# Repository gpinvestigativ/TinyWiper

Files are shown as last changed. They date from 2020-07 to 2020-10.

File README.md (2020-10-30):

# TinyWiper - a portable SD card wiper

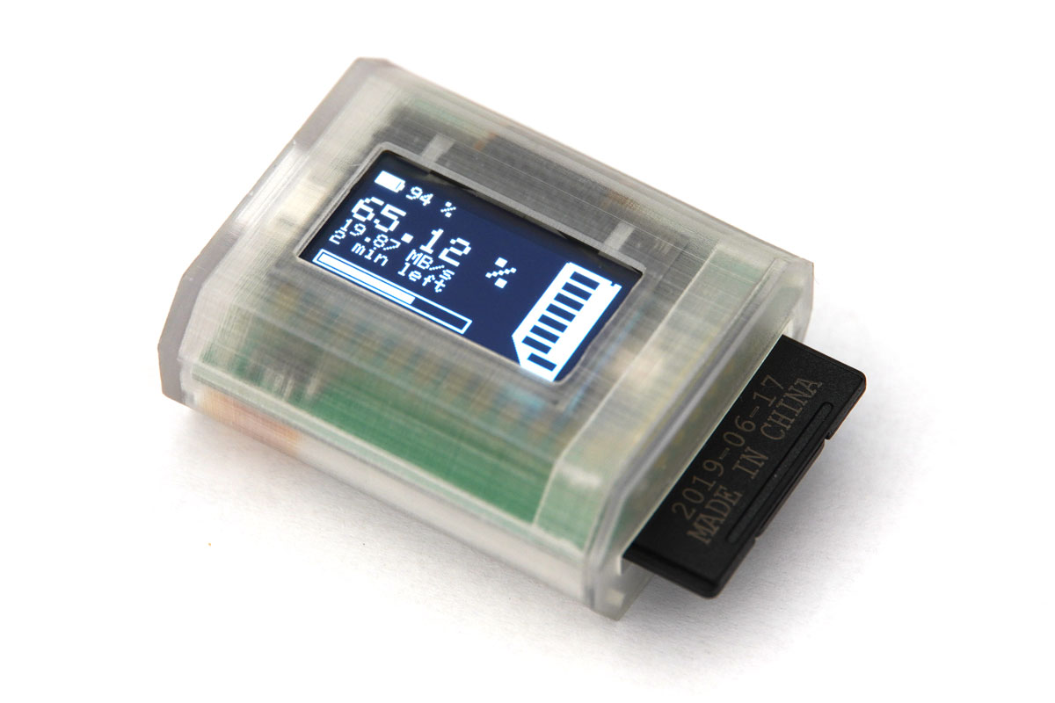
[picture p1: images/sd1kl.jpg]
Image of TinyWiper


The TinyWiper is a small, battery powered device which securely deletes your SD cards by overwriting the whole card with randomly generated data.  

> *Note:* this is an successor project to the [SDCardWiper](https://github.com/gpinvestigativ/SDCardWiper) Project, which is based on a Raspberry Pi Zero and readily available parts.  

Just formating your SD card does not delete its contents, it just makes them invisible within the filebrowser of your operating system. Forensic software can often easily reconstruct data on deleted or formated SD cards.  

If you want to make sure that your data can not be reconstructed, this device will securely erase your SD cards.

## Hardware

* Teensy 4.0 as MCU
* Custom PCB
* 128x64 I2C OLED Display
* Full Size SD Card Slot
* 400 mAh Lipo Battery ~ 2h battery life
* Mirco USB for fimware update & battery charging
* Hardware on/off switch
* 3D printed case

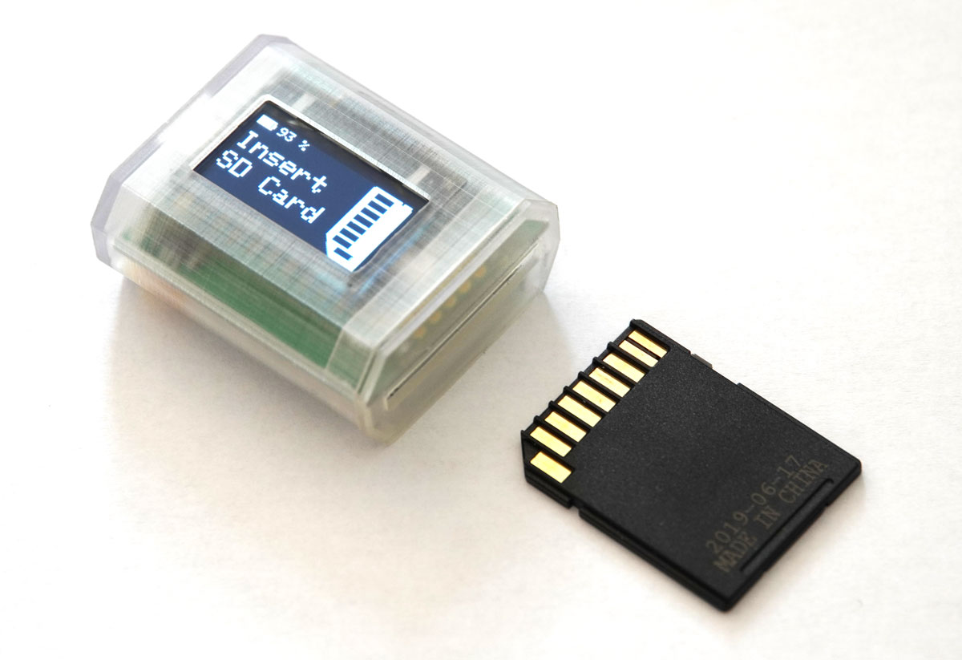
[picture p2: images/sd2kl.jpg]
Image of TinyWiper


## Software

* True random number generator used to initialize PRNG
* automatically detect SD card, start wiping automatically after timeout
* every Nth 512byte Block, generate a new random buffer (for speedup purposes currently every 10th block)
* keep track of successfully written blocks, try to re-write failed blocks at the end
* format card after wiping
* shows successrate at the end of the process

# DIY Version
Part of the reason there is a custom PCB for the TinyWiper was, that at the time of development only the Teensy4.0 was available which had it's high speed SDIO pins at a very DIY inconvenient place.  
Recently the Teensy4.1 was released which conveniently has a micro SD card slot. Therefore I decided to make a compatible firmware for the T4.1 for people who want to build a quick DIY version of the TinyWiper. You can find this firmware in the [t41port](https://github.com/gpinvestigativ/TinyWiper/tree/t41port) branch.

## Setup
If you don't want to build the firmware yourself you can find precompiled binaries under the releases tab.

To flash the binaries you need the the [Teensy Loader](https://www.pjrc.com/teensy/loader.html) Application.

**Caution:** the button on the Teensy is a reset button, be careful not to press it accidentally while wiping an SD Card. You could also make a little protective cover for the button.

LED pattern | meaning 
---|---
t41idle | Idle - insert SD card
t41idle | wiping - 10% done 
t41idle | wiping - 80% done 
t41idle | wiping finished - remove sd card

## Q&A

*Q: Why not use a secure erase software on a computer like the security options within macs disk manager?*  
A: While it is totaly viable to use secure erase software options for this task, the TinyWiper has 3 major advantages:
* TinyWiper is highly portable. You can carry it in your pocket in the field and use it standalone without having to use a computer.
* Securely wiping SD cards is time consuming. It easily blocks the sd card slot on your computer for several hours. Overwriting a 64GB SD card can take between 1-2 hours, 400GB multiple hours.
* Software that runs on your computer can much easier be infiltrated by a virus or an attacker. The TinyWiper is an unteathered device, which makes it impossible to hack without physical access to it.

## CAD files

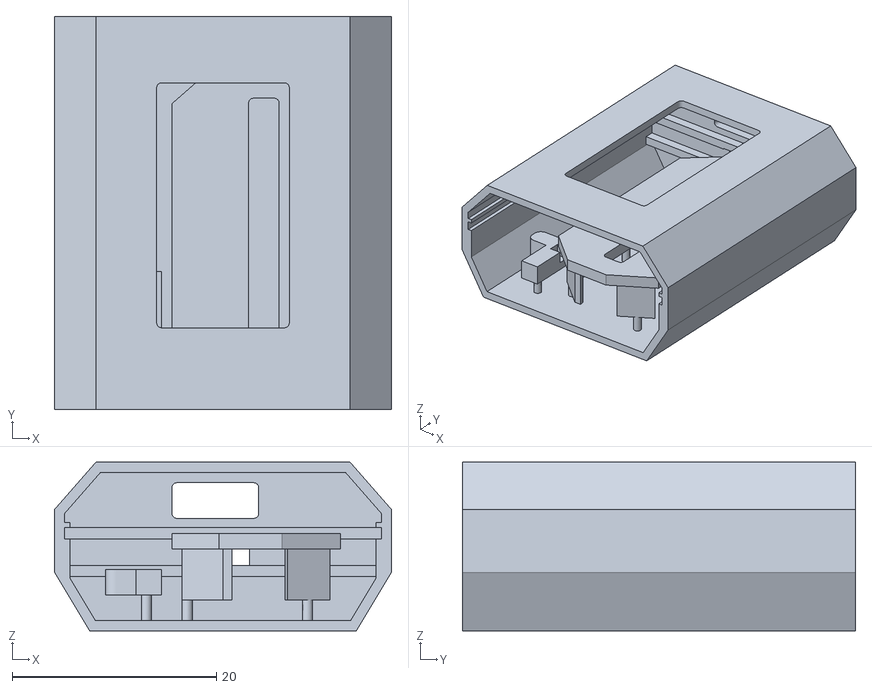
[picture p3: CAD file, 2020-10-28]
hardware/case.stl
33.0 x 38.5 x 16.5

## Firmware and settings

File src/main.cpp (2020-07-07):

#include <Arduino.h>
#include <vector>

#include "SdFat.h"
#include <sdios.h>
#include "FreeStack.h"
#include <Wire.h>
#include <Adafruit_GFX.h>
#include <Adafruit_SSD1306.h>

#include "data.h"
#include <trng.h>

//#define DEBUG_BATT
#define FORMATCARD

#define VERSION 0.2

const float analogDivider = 160.0f;

#define cardDetectPin 23
#define writeProtectPin 22
#define DISPLAY_RST_PIN 15

const size_t BUF_SIZE = 512;

#define SD_CONFIG SdioConfig(FIFO_SDIO)

//==============================================================================
// End of configuration constants.
//------------------------------------------------------------------------------

// Insure 4-byte alignment.
uint32_t buf32[(BUF_SIZE + 3) / 4];
uint8_t* buf = (uint8_t*)buf32;

SdioCard sd;

Adafruit_SSD1306 display(128, 64, &Wire, DISPLAY_RST_PIN, 4000000UL, 100000UL);

ArduinoOutStream cout(Serial);

void cidDmp() {
  cid_t cid;
  if (!sd.readCID(&cid)) {
    cout << "CID Error" << endl;
  }
  cout << F("\nManufacturer ID: ");
  cout << hex << int(cid.mid) << dec << endl;
  cout << F("OEM ID: ") << cid.oid[0] << cid.oid[1] << endl;
  cout << F("Product: ");
  for (uint8_t i = 0; i < 5; i++) {
    cout << cid.pnm[i];
  }
  cout << F("\nVersion: ");
  cout << int(cid.prv_n) << '.' << int(cid.prv_m) << endl;
  cout << F("Serial number: ") << hex << cid.psn << dec << endl;
  cout << F("Manufacturing date: ");
  cout << int(cid.mdt_month) << '/';
  cout << (2000 + cid.mdt_year_low + 10 * cid.mdt_year_high) << endl;
  cout << endl;
}

void drawBattery(int offX = 0, int offY = 0) {
  static int battLutOffset = 540;
  int aread0 = analogRead(0);

  #ifdef DEBUG_BATT
  cout << F("Aread 0: ") << aread0 << endl;
  #endif

  int battLutIdx = aread0 - battLutOffset;
  battLutIdx = constrain(battLutIdx, 0, 130);
  int battPercent = battLut[battLutIdx];
  int battBarValue = round((float)battPercent / 100.0f * 11);
  display.drawRect(offX, offY, 12, 7, SSD1306_WHITE);
  display.fillRect(offX, offY, battBarValue, 7, SSD1306_WHITE);
  display.drawLine(offX + 12, offY + 2, offX + 12, offY + 4, SSD1306_WHITE);
  display.setTextSize(1);
  display.setCursor(offX + 17, offY);
  display.setTextColor(SSD1306_WHITE);
  display.print(battPercent); display.print(" %");
}

void showStartScreen() {
  static int aniCount = 0;
  display.clearDisplay();
  display.drawBitmap(128 - (aniCount > 35 ? 35 : aniCount), 1, sdCardBitmap, 77, 62, SSD1306_WHITE);
  aniCount += 1;
  if (aniCount > 50) aniCount = 0;
  drawBattery();
  display.setTextColor(SSD1306_WHITE);
  display.setTextSize(2);
  display.setCursor(0, 15); display.print("Insert");
  display.setCursor(0, 35); display.print("SD Card");
  display.display();
}

//------------------------------------------------------------------------------
void setup() {
  display.begin(SSD1306_SWITCHCAPVCC, 0x3C);
  display.setRotation(2);

  // display.clearDisplay();
  // display.drawBitmap(0, 0, gpi, 128, 64, SSD1306_WHITE);
  // display.display();
  // delay(200);
  
  display.clearDisplay();
  display.drawBitmap(0, 0, tinyWiper, 128, 64, SSD1306_WHITE);
  display.setTextColor(SSD1306_WHITE);
  display.setCursor(105, 49);
  display.setTextSize(1);
  display.print(VERSION,1);
  display.display();


  pinMode(cardDetectPin, INPUT_PULLUP);
  pinMode(writeProtectPin, INPUT_PULLUP);

  Serial.begin(115200);
  //while (!Serial);

  // use uppercase in hex and use 0X base prefix
  cout << uppercase << showbase << endl;

  trng_init();
  uint32_t tword = trng_word();
  //cout << "random seed: " << tword << endl;
  srandom(tword);
  delay(1000);
}
//------------------------------------------------------------------------------
void loop() {
  uint32_t t = 0;
  int durationMinutes = 0;
  bool writable = false;
  bool randWriteCompleted = false;
  bool formatCompleted = false;

  //wait for card insert
  while (digitalRead(cardDetectPin) == 1) {
    showStartScreen();
    delay(50);
  }
  delay(100);

  #ifdef WRITEPROTECTCHECK
  if (digitalRead(writeProtectPin) == 0) {
    delay(500);
    if (digitalRead(writeProtectPin) == 0)
      writable = true;
    else
      writable = false;

  } else {
    writable = false;
  }
  #else
  writable = true;
  #endif


  while (!sd.begin(SD_CONFIG)) {
    if (digitalRead(cardDetectPin) == 1) break;
  }

  cout << F("Card size: ") << sd.sectorCount() * 512E-9;
  cout << F(" GB (GB = 1E9 bytes)") << endl;
  cout << F("Speed: ") << sd.kHzSdClk() << F(" kHz") << endl;
  cout << F("sectorCount: ") << sd.sectorCount() << endl;

  cidDmp();

  //pre wipe info screen
  int aniCount = 64;
  while (aniCount > 0) {
    display.clearDisplay();
    drawBattery();
    display.drawBitmap(100, 1, sdCardBitmap, 77, 62, SSD1306_WHITE);
    display.setTextColor(SSD1306_WHITE);
    display.setCursor(0, 15);
    display.setTextSize(2);
    display.print(sd.sectorCount() * 512E-9); display.println(" GB");
    display.setTextSize(1);
    display.print(sd.kHzSdClk() / 1000); display.println(" MHz");
    if (writable)
    {
      display.setCursor(0, 55);
      display.println("Starting Wipe...");
      display.drawLine(0, 63, 128 - aniCount * 2, 63, SSD1306_WHITE);
      aniCount--;
    } else {
      display.setCursor(0, 56);
      display.println("SD Card locked");
    }
    display.display();
    delay(30);
    if (digitalRead(cardDetectPin) == 1) break;
  }

  //actual wiping
  int failedSectorCount = 0;
  std::vector<unsigned int> failedSectors;
  #if 1
  if (digitalRead(cardDetectPin) == 0) {
    cout << F("Starting full disk wipe") << endl << endl;
    t = millis();
    uint32_t lastT = t;
    for (unsigned int i = 0; i < sd.sectorCount(); i++) {
      if (i % 10 == 0) {
        for (size_t i = 0; i < BUF_SIZE/4; i++) {
          buf32[i]= random();
        }
      }
      auto startus = micros();
      bool writeStatus = sd.writeSector(i, buf);

      if(!writeStatus){ //error handling
        cout << (int)sd.errorCode() << " ";
        printSdErrorSymbol(&Serial, sd.errorCode());
        cout << " ";
        printSdErrorText(&Serial, sd.errorCode());
        cout << endl;
        failedSectorCount++;
        failedSectors.push_back(i);
      }
      if(micros()-startus > 888888){ //hacky fix for random SD Card errors
        cout << "restart sd " << i << endl;
        sd.begin(SD_CONFIG);
      }

      if ((millis() - lastT) > 1000) {
        lastT = millis();
        uint32_t usedtime = millis() - t;
        double msPerSector = (double)usedtime / (double)i;
        uint32_t sectorsLeft = sd.sectorCount() - i;

        //cout << ((double)i/(double)sd.sectorCount())*100 << " % - " << i*512E-3/usedtime << " MB/s - " << usedtime << " " << msPerSector << " " << sectorsLeft << " " << (sectorsLeft*msPerSector)/60000 << " min left"<< endl;

        display.clearDisplay();
        drawBattery();
        display.drawBitmap(100, 1, sdCardBitmap, 77, 62, SSD1306_WHITE);
        display.setTextColor(SSD1306_WHITE);
        display.setCursor(0, 15);
        display.setTextSize(2);
        double progress = ((double)i / (double)sd.sectorCount()) * 100;
        display.print(progress); display.println(" %");
        display.setTextSize(1);
        display.print(i * 512E-3 / usedtime); display.println(" MB/s");
        display.print((int)((sectorsLeft * msPerSector) / 60000)); display.println(" min left");
        display.drawRect(0, 52, 80, 8, SSD1306_WHITE);
        display.fillRect(2, 54, (int)round(progress * 0.76), 4, SSD1306_WHITE);
        display.display();
        if (digitalRead(cardDetectPin) == 1) break;
      }
      if (digitalRead(cardDetectPin) == 1) break;
      if (i == sd.sectorCount() - 1)
        randWriteCompleted = true;
    }
  }
  #endif

  //retry failed Sectors
  #if 1
  //for(int x = 0; x < 8000; x++)failedSectors.push_back(x);

  cout << "retry " << failedSectors.size() << " failed sectors";
  uint32_t lastT = t;
  uint32_t curSector = 0;
  for(auto sec : failedSectors){
    int secRetries = 5;
    curSector++;
    for (size_t i = 0; i < BUF_SIZE; i += 4) {
      buf[i] = random();
    }
    while(secRetries-- > 0){
      auto startus = micros();
      if(sd.writeSector(sec, buf)){
        secRetries = 0;
        failedSectorCount--;
      }
      if(micros()-startus > 888888){ //hacky fix for random SD Card errors
        cout << "restart sd " << sec << endl;
        sd.begin(SD_CONFIG);
      }
    }

    if ((millis() - lastT) > 200) {
      lastT = millis();
      uint32_t usedtime = millis() - t;
      double msPerSector = (double)usedtime / (double)curSector;
      uint32_t sectorsLeft = failedSectors.size() - curSector;

      //cout << ((double)i/(double)sd.sectorCount())*100 << " % - " << i*512E-3/usedtime << " MB/s - " << usedtime << " " << msPerSector << " " << sectorsLeft << " " << (sectorsLeft*msPerSector)/60000 << " min left"<< endl;

      display.clearDisplay();
      drawBattery();
      display.drawBitmap(100, 1, sdCardBitmap, 77, 62, SSD1306_WHITE);
      display.setTextColor(SSD1306_WHITE);
      display.setCursor(0, 15);
      display.setTextSize(1);
      display.println("Retry failed");
      display.println("sectors...");
      double progress = ((double)curSector / (double)failedSectors.size()) * 100;
      //display.print(curSector * 512E-3 / usedtime); display.println(" MB/s");
      display.print(progress); display.println(" %");
      //display.print((int)((sectorsLeft * msPerSector) / 60000)); display.println(" min left");
      display.drawRect(0, 52, 80, 8, SSD1306_WHITE);
      display.fillRect(2, 54, (int)round(progress * 0.76), 4, SSD1306_WHITE);
      display.display();
      if (digitalRead(cardDetectPin) == 1) break;
    }
  }
  cout << "finished, " << failedSectorCount << " sectors couldn't be deleted" << endl;
  #endif

  //FORMAT SD Card after random data write
  // SdCardFactory constructs and initializes the appropriate card.
  #ifdef FORMATCARD
  if (digitalRead(cardDetectPin) == 0) {
    cout << "try formating card now " << endl;
    int formatTries = 10;
    while(formatTries-- > 0 && !formatCompleted){
      cout << "Try Format " << 10-formatTries << endl;
      formatCompleted = true;
      SdCardFactory cardFactory;
      SdCard* m_card = cardFactory.newCard(SD_CONFIG);
      if (!m_card || m_card->errorCode()) {
        cout << "card init failed" << endl;
        formatCompleted = false;
      }
      uint8_t  sectorBuffer[512];
      FatFormatter fatFormatter;
      if (!fatFormatter.format(m_card, sectorBuffer, &Serial)) {
        cout << "card format failed" << endl;
        formatCompleted = false;
      }
    }
  }
  #endif

  t = millis() - t;
  durationMinutes = (int)round((t / 60000));
  cout << endl << F("Done") << endl;

  float successRate = ((float)(sd.sectorCount()-failedSectorCount)/(float)sd.sectorCount())*100.0f;

  cout << sd.sectorCount() << " f: " << failedSectorCount << endl;

  //wait for card disconnect
  aniCount = 28;
  int cardDetectCounter = 0;
  while (cardDetectCounter < 10) {
    if(!digitalRead(cardDetectPin)){
      cardDetectCounter = 0;
    }else{
      cardDetectCounter++;
    }
    display.clearDisplay();
    display.drawBitmap(128 - aniCount, 1, sdCardBitmap, 77, 62, SSD1306_WHITE);
    aniCount -= 1;
    if (aniCount < -20) aniCount = 28;
    drawBattery();
    display.setTextColor(SSD1306_WHITE);

    if (randWriteCompleted) {
      display.setTextSize(2);
      display.setCursor(0, 15); display.print("Finished");
      display.setTextSize(1);display.setTextSize(1);
      display.setCursor(0, 35); display.print(durationMinutes); display.println(" min");
      display.setCursor(0, 46); display.print(successRate); 
      if(formatCompleted)
        display.println(" % success");
      else
        display.println(" % success.");
    } else if (!randWriteCompleted && formatCompleted) {
      display.setTextSize(2);
      display.setCursor(0, 15); display.print("Error");
      display.setTextSize(1);
      display.setCursor(0, 35); display.print("Wipe failed");
    } else {
      display.setTextSize(2);
      display.setCursor(0, 15); display.print("Error");
      display.setTextSize(1);
      display.setCursor(0, 35); display.print("all failed");
    }
    display.setTextSize(1);
    display.setCursor(0, 56);
    display.println("remove SD Card");
    display.display();
    delay(50);
  }
}

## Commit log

2020-07-02 stability fix, sector write success rate display
    [main.cpp]
2020-07-03 retry failed sectors added version variable & display
    [main.cpp]
2020-07-03 fixed random buffer filling
    [main.cpp]
2020-10-28 added case 3d printing files
    [case.stl]
